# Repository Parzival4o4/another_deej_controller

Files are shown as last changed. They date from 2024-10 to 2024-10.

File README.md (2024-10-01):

# another_deej_controller

This project features an under-the-desk-style volume mixer with six rotary encoders for controlling individual audio channels on your PC, a display for visual feedback, and an air quality sensor that I had lying around.

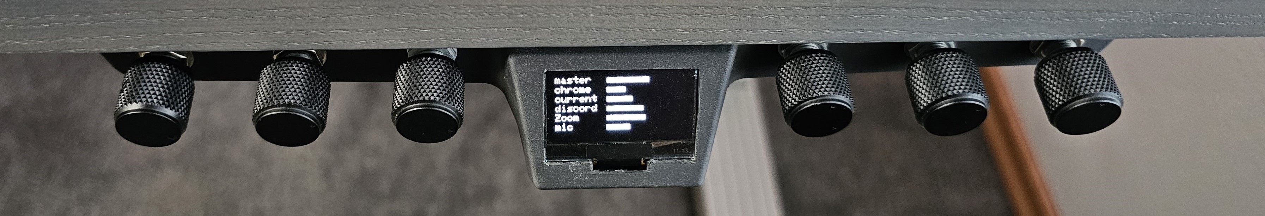
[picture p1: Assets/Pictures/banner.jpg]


For those who don’t know what Deej is: 
Deej is an open-source project by omriharel that enables users to control individual application audio levels on your PC using a DIY Volume Mixer.

My project focuses on building a volume mixer with additional advanced features. For the mixer to function, the PC still needs to be running the Deej software, which you can get from omriharel's [deej project github page](https://github.com/omriharel/deej)

The primary aim of this project was to learn and gain hands-on experience, so I decided to incorporate some non-essential features, which added complexity. If you're looking to build a more basic volume mixer, I highly recommend following the instructions provided by the original Deej project.

# Overview
Cutting_Diagram

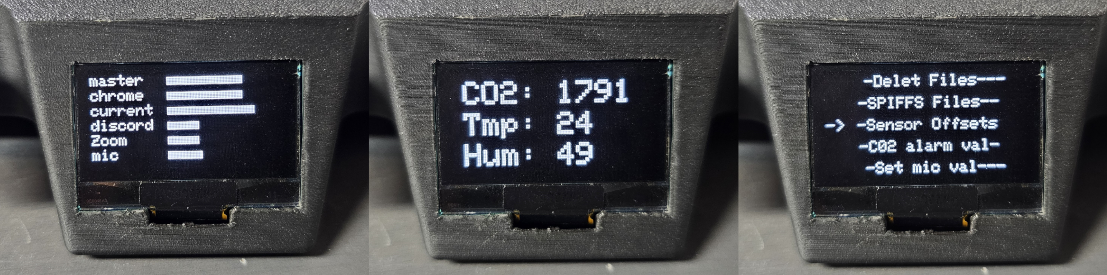
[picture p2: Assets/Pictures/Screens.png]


## How to use

While the mixer controls six volume levels, the channels are not mapped one-to-one with the rotary encoders. I found that I only need fine control over five audio channels: Master, Chrome, Current, Discord, and Zoom.

For my microphone, I prefer it either completely muted or set to its default volume (roughly 43%). Because of this, Encoder 4 is dedicated to controlling device settings, and the microphone volume is instead managed with the buttons on Encoders 5 and 6.

Here’s an overview of what each encoder does on the home screen (encoders numbered from left to right):

| Encoder # | Label | Rotation | Short Press | Long Press | Hold |
| --- | --- | --- | --- | --- | ---|
| 1 | MasterVolume | Volume up/down | Mute/Unmute | Save current volume levels | - |
| 2 | Chrome | Volume up/down | Mute/Unmute | Turn screen off (screen will turn back on when any encoder is rotated or pressed) | - |
| 3 | Current | Volume up/down | Mute/Unmute | - | - |
| 4 | Menu Encoder | Enter settings | Show air quality | - | - |
| 5 | Discord | Volume up/down | Mute the mic channel | Unmute mic channel | - |
| 6 | Zoom | Volume up/down | - | - | Boost mic channel to 100% (for when you need to win an argument 😉)  |
 
## Other random Features

- **Sleep Mode**: If the IR sensor doesn't detect your presence, the screen will turn off until you return to your desk or move one of the knobs.

- **CO2 Alert**: If the CO2 sensor detects that levels exceed the set threshold (which can be configured in the settings menu), an alert will display on the screen, reminding you to let in some fresh air. You can dismiss the alert by moving any of the knobs, but it will return after 15 minutes if levels remain high.

- **Saving Slider Values**: By long-pressing Encoder 1, the current slider values will be saved to local storage. When the device restarts, these values will be loaded automatically (even after a power loss).

# Build 

I attempted to minimize soldering as much as possible. However, since the pins on the encoders are too small to securely fit standard jumper cables, soldering the cables to the pins is necessary.

## Parts

| Quantity | Part | 
| --- | --- |
| 6x | Rotary encoder with switch, 20 pulses per revolution (EN11-HSM1BF20 or EC11)
| 6x | Knob for rotary shaft, 6mm (pay attention if your encoders have D-type or star shape shaft)
| 1x | ESP32 Development Board (preferably with USB-C)
| 1x | PCF8575 IO Expander I2C (16IO pins)
| 1x | SCD40 or SCD41 CO₂ Sensor I2C (optional)
| 1x | AM312 DC 2.7-12V PIR Human Sensor
| 1x | 1.3-Inch OLED Display I2C (not SPI)
| 1x | Breadboard (MB-102)
| ?x | Some jumper cables
| 4x | M3 screws (no longer than 8mm)
| 1x | Double-sided tape
| (1x) | 3D printed case

## Flash ESP32

1. Download the Arduino IDE  https://www.arduino.cc/en/software

2. Pull the Arduino project directory from this repository.

3. On your local system, navigate into the directory and open any of the `.ino` files with the Arduino IDE. The rest of the project files should load automatically 

4. Use the Board Manager to install the ESP32 package by Espressif Systems (version 3.0.5).

5. Use the Library Manager to install the following libraries:
   - **PCF8575** (by Rob Tillart, version 0.2.3)
   - **Sensirion I2C SCD4X** (by Sensirion, version 0.4.0)
   - **Adafruit SH110X** (by Adafruit, version 2.1.11)

6. Select the board under **Tools** -> **Board**.

7. Select the COM port that your ESP32 is connected to.

8. Click the **Upload** button.

    (you might need to hold down the boot button on your ESP23 board during the Upload)

## 3D Printing

The case could still use some optimization to improve printability.

- The main body must be printed with supports, which can be tricky to remove from the cavity in the display section. I had good results using tree supports.
    
    Even with perfect print quality, my design makes it difficult (but not impossible) to maneuver the display into place.

- The lid is printed standing on edge. The model includes some stabilizing fins to prevent it from falling over during printing. Due to the small contact area with the bed, you might also want to use a brim.

If you use Bambu Studio, you can grab the *Case_BambuStudio.3mf* file with all the settings that worked for me. If not, you can use the STEP files. I also included the Autodesk Fusion project if you want to make changes to the model.

## Assembly  

### 1. Cutting the breadboard

The case is too small for a full-sized breadboard to fit, but a half-sized breadboard is too small to accommodate all the components. So, a full-sized breadboard needs to be cut down.

Additionally, the breadboard needs to be split down the middle due to the wide footprint of the ESP32.

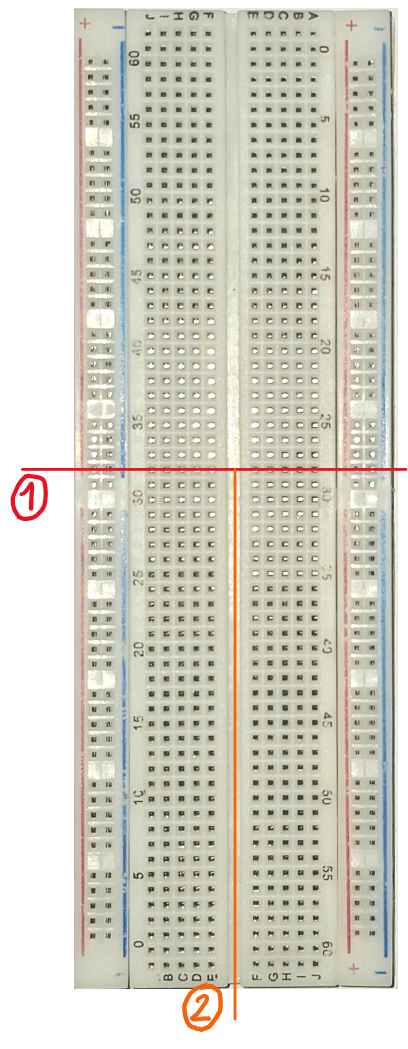
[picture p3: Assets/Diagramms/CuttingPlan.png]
Cutting_Diagram


### 2. Encoder prep:

I prefer smooth rotary encoders for my volume control, but I found no place to buy them. Luckily, it’s possible to modify a step encoder. (If you choose to modify your encoders, keep one stock as the menu encoder should have steps.)

- **Step 1**: Open the encoder.
- **Step 2**: Locate the spring that pushes on the notches.
- **Step 3**: Rip out the spring.
- **Step 4 (optional)**: Add some thick **NON-CONDUCTIVE** grease (I used silicone grease). The grease will increase resistance during rotation, making the encoder feel smoother.
- **Step 5**: Reassemble the encoder.

### 3. Wiring
    
1. Start by populating the breadboard as shown below:

    (For the connections on the breadboard, use small bent wire.)

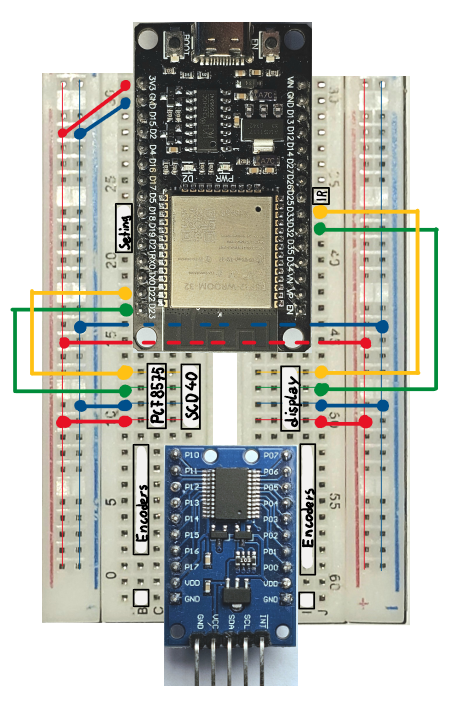
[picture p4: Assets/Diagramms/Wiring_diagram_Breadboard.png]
Wiring_Diagram 1
    

2. Next, solder the jumper cables to your encoders.
3. Solder the ground wires to the encoders (you should have two sets of three encoders).
4. Now, plug everything together.

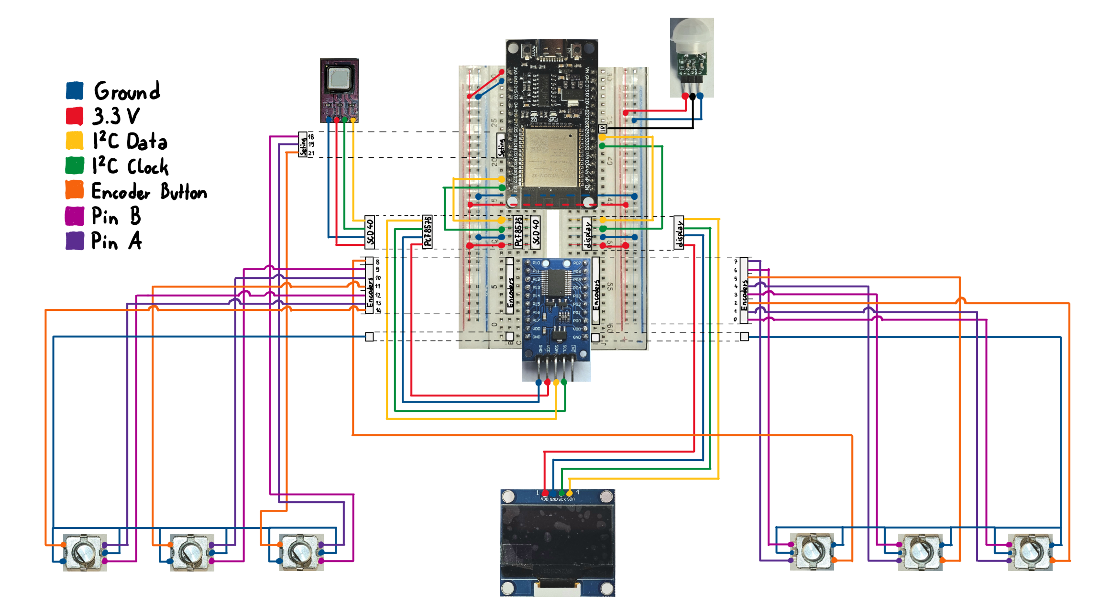
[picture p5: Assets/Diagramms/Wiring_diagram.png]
Wiring_Diagram 3
    

### 4. Stuff everything into the Case

- Use some double-sided tape to hold the SCD40 sensor in place.

- The display can be quite tricky (sorry):

    Cut off the small part of the connector pins sticking out the front; this will allow the display to sit flush.

    Maneuver the display into place. Depending on your print quality, you might need to clean up the print.

    Once in place, tape or glue it down to ensure it doesn't accidentally get pushed back into the case later.

- Stick down the breadboard with the port of the ESP32 sticking out the back. This will allow you to access the reset and boot buttons.

- Bend over the jumper cables on the breadboard. I wanted to make the case as thin as possible, and if the jumper cables stick straight up, the lid can't be closed. 

- Everything else should be straightforward.

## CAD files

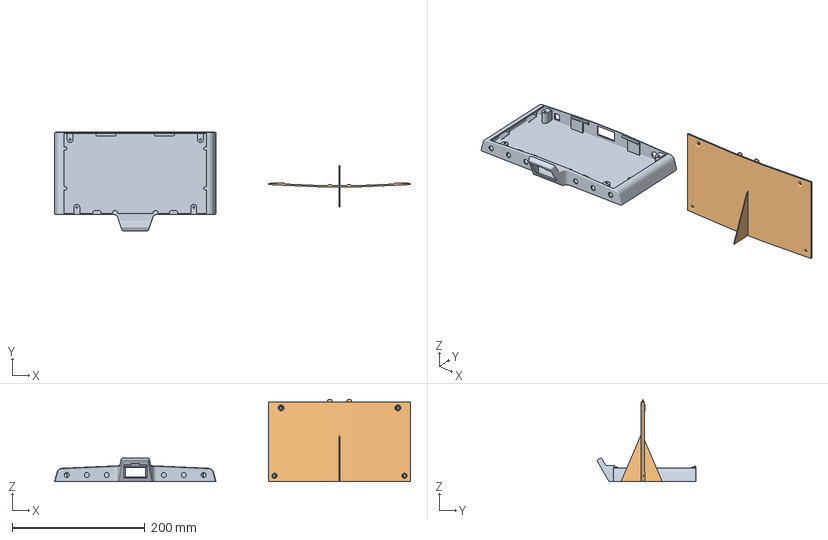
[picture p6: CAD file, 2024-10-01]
Case/Case_BambuStudio.3mf
535.6 x 148.2 x 123.9 mm
Deej Case.step
Deej Deckel.step

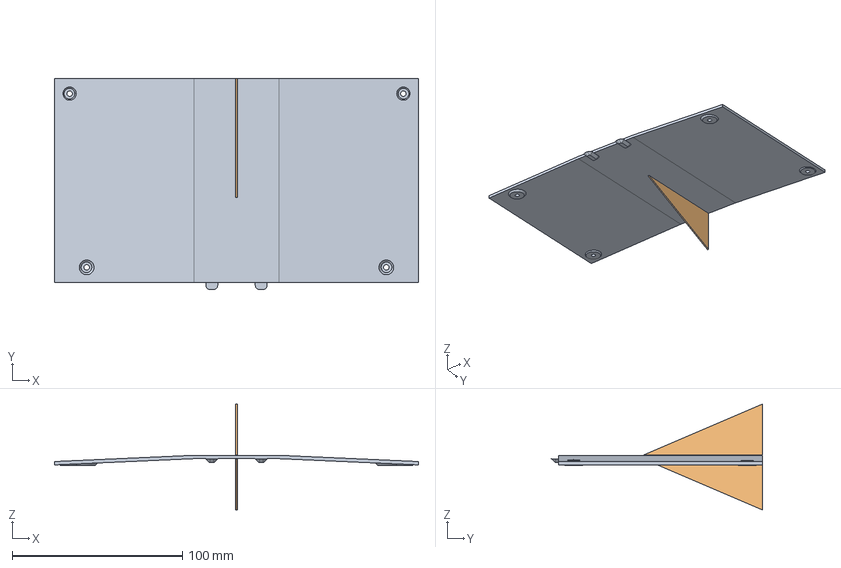
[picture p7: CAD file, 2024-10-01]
Case/Step_Files/case_lid_supported.step
213.7 x 123.9 x 62.2 mm

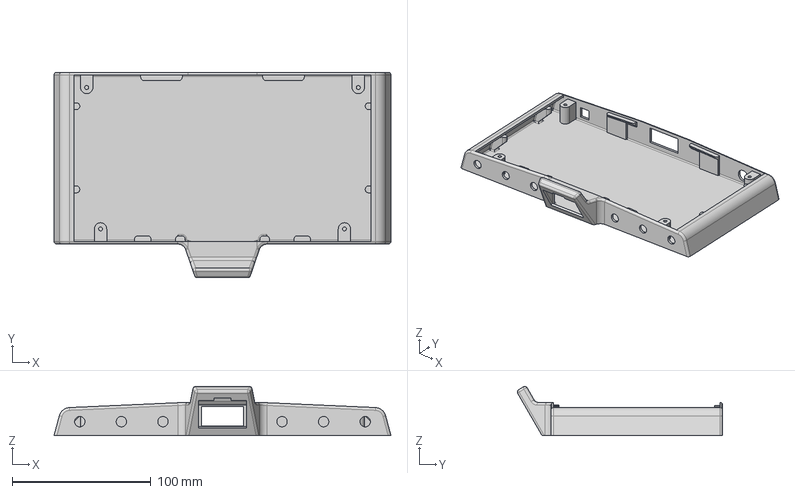
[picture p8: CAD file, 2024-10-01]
Case/Step_Files/case_body.step
243.1 x 148.2 x 35.4 mm

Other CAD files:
Case/Autodesk_Fusion_Project/deej_controller.f3d

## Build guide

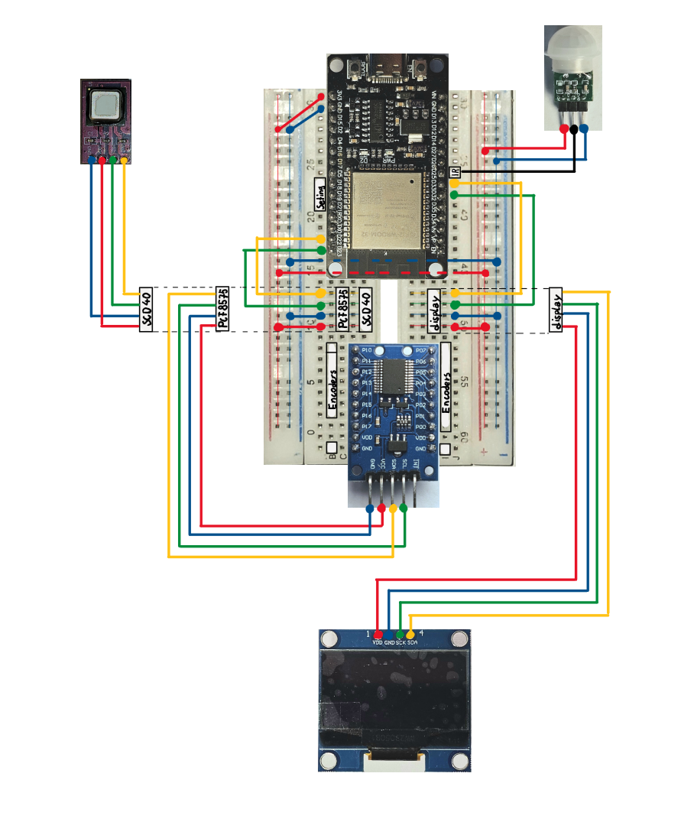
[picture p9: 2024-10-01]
Assets/Diagramms/Wiring_Diagram_No_Encoder.png

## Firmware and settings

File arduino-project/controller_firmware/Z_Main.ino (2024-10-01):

//######################################################################
//##############        _      ____   ____  _____         ##############
//##############       | |    / __ \ / __ \|  __ \        ##############
//##############       | |   | |  | | |  | | |__) |       ##############
//##############       | |   | |  | | |  | |  ___/        ##############
//##############       | |___| |__| | |__| | |            ##############
//##############       |______\____/ \____/|_|            ##############
//##############                                          ##############
//######################################################################


long display_time = 0;

long my_time = 0;
void loop() {
  //long time2 = micros() - my_time;
  //my_time = micros();
  //println("time = " + String(time2) + " free heap: " + String(ESP.getFreeHeap()));
  //println(String(time2));


  // ====== Check panic ======
  if (loop_debug()) { return; }

  // ====== sensors ======
  std::vector<std::unique_ptr<StateChange>> sensors;
  I_state.check_sensors(sensors);
  for (const auto& sc : sensors) {
    mm.handle_sensors(sc, &state);
  }

  // ==== user input ====
  std::vector<std::unique_ptr<StateChange>> inputs;
  I_state.check_input(inputs);
  if (!inputs.empty()){
    state.action(); 
  } else if (millis() - state.get_last_action() > (SCREEN_TIMEOUT * 60000)) {
    inputs.push_back(make_unique<InactiveChange>(true));
  }
  // call mode handler
  // call default handler
  for (const auto& sc : inputs) {
    mm.handle_input(sc, &state);
  }

  // ==== idle tasks ====
  mm.idle_task(&state);
  
  // === display/send ===
  state.get_deej()->send_sliders();
  mm.display_state(&state);


  //println(String(micros() - my_time));
}

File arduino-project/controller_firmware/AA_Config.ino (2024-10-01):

//################################################
//                  Hardware
//################################################

//---- Wire 0 ----
// IO expander, scd4X,
//esp8266 scl = D1 = 5; sda = D2 = 4
//esp32
#define WIRE0_SCL 23        //positive int (esp pin)
#define WIRE0_SDA 22        //positive int (esp pin)
#define WIRE0_SPEED 400000  // default speed is 100000 max is 400000 oc up to 700000

//---- Wire 1 ----
// Display (sending a new frame to a display can take around 30 ms, which is wy it gets its own bus and threat)
// esp32 (in my configuration): scl = 32, sda = 33
#define WIRE1_SCL 32        //positive int (esp pin)
#define WIRE1_SDA 33        //positive int (esp pin)
#define WIRE1_SPEED 100000  // default speed is 100000 max is 400000 oc up to 700000


//---- PCF8575 ----
#define PCF8575_ADDRESS 0x20  // default address is 0x20 (address min 0x20 max 0x27)

//---- SCD4X Sensor ----
#define SCD_interval_slow 60000  //SCD_interval_slow>0 // millis between measurements
#define SCD_interval_fast 5000   //SCD_interval_fast>0 // millis between measurements

//---- Movement Sensor ----
#define MOTION_PIN 25          //positive int (esp pin) // GPIO 25 in my build
#define Movement_interval 2000  //Movement_interval > 0 // most movement sensor hold the pin signal for some time

//---- Encoder -----
#define ENCODER_COUNT 6  //number of encoders (int)

#define ENCODER_PIN_A \
  { 1, 4, 7, 19, 10, 13 }  //int[]
#define ENCODER_PIN_B \
  { 0, 3, 6, 18, 9, 12 }  //int[]
#define ENCODER_PIN_S \
  { 2, 5, 8, 21, 11, 14 }  //int[]
#define ENCODER_CONNECTED_TO \
  { 1, 1, 1, 0, 1, 1 }  //int[] // 1 connoted to IO Expander 0 connected to ESP

#define ENCODER_MENU 3  //int //if you want to change this you probably will need to change more in the code just leaf it at 3 // 0 < ENCODER_MENU < ENCODER_COUNT

#define ENCODER_ROT_CHANGE_BLOCK_TIME 1  // millis > 0 // blocks a change in rotation direction for the number of millis

//---- Display ----
#define SCREEN_WIDTH 128  //int //program dose not support scaling.
#define SCREEN_HEIGHT 64  //int //dont change
#define FPS 28            //int // min=1 max=30


//################################################
//                  Software
//################################################

//---- file system ----
#define FILE_NAME_SLIDER_VALUES "/slider_values.bin"
#define FILE_NAME_STATE_CONFIG "/state_config.bin"


//---- Serial speed ----
#define SERIAL_SPEED 4800 //115200  //int

//---- Encoder and swich stuff ----
#define IGNORE_ROTATION_TIME 20  // millis, for how long should rotation be ignored after button release

//        once rotation on one encoder is detected all other encoders will be ignored (both button and rotation)
//        this PRIO_TIME defines for how long after the rotation ends the encoder will be prioritized
#define PRIO_TIME 100

//---- Screen off timer -----
#define SCREEN_TIMEOUT 10  // minutes, how long should the program wait to turn of the screen

//---- deej ----
#define DELAY_AFTER_SENDING 8  //positive // millis
#define SLIDER_COUNT 6         // positive // this dose not have to be the same value as ENCODER_COUNT
#define DEFAULT_PERCENT \
  { 75, 50, 50, 75, 50, 43 }  // default volume levels

#define MIC_BOOST_PERCENT 100  // positive 0-100 
#define DEAD_ZONE_PERCENT 50   //  0<= DEAD_ZONE_PERCENT <= 100

#define DEEJ_MAX_VAL 1023  //dont change this // should be 1023

//---- co2 alarm ----
#define CO2_ALARM_LEVEL 1100 //int > 0 //by default if co2 is higher than this an alarm is triggered 

#define CO2_ALARM_MUTE_TIME 15 //int > 0 //minutes 

//################################################
//                  Input
//################################################

//---- switch ----
// any press less than this is short every thing more is a long press
#define SHORT_PRESS_CUT_OF 650  // int, positive, millis


//################################################
//                  Debug
//################################################
#define DEBUG false  //bool //prints free heap and some test text if defined

#define PRINT_ERR true  //bool

#define ENABLE_PANIC true  //bool //true: errors will break the program; false: errors will cause undefined behavior

#define DEEJ_PRINT true  //bool //for debuting it can be useful to disable the deej messages

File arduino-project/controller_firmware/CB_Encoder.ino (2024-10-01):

PCF8575 PCF(0x20, &Wire);

//##########################################
class Encoder_State {
  //########################################
  /**this represents a single encoder**/
protected:
  //pins
  int pin_a;
  int pin_b;
  int pin_s;
  int connected_to;
  //rot state
  int old_rot_pos = 0;
  int rot_dir = 0;
  unsigned long state_time = 0;  // millis();  //time since state change (if a skip is detected this is not updated)
  //switch state
  bool old_switch_state = false;
  bool is_long_press = false;
  int switch_press_start = -1;
  static constexpr int debounce = 5; //ms // time after state change that further state change is ignored;
  long debounce_time = 0; 

  bool read_pin(int16_t pinStates, int pin) {
    switch (connected_to) {
      case 0:
        return !digitalRead(pin);
      case 1:
        return !bitRead(pinStates, pin);
      default:
        my_panic("connection type is not supported check the ENCODER_CONNECTED_TO array in the config");
        return 0;
    }
  }

  int read_rot_pos(int16_t pinStates) {
    bool A = read_pin(pinStates, pin_a);
    bool B = read_pin(pinStates, pin_b);
    if (A && B) {
      return 0;
    } else if (!A && B) {
      return 1;
    } else if (!A && !B) {
      return 2;
    } else if (A && !B) {
      return 3;
    }
    my_panic("reached unreachable code in read_rot_pos()");
    return 0;
  }

  SWITCH_PRESS checkSwitch(bool new_switch_state) {
    //== debounce ==
    if (new_switch_state != old_switch_state) {
      if ((millis() - debounce_time) > debounce){
        //outside of debounce time -> allow state change and begin debounce time;
        debounce_time = millis();
      } else {
        //within debounce time -> dont allow state change 
        if (old_switch_state){
          return PRESSED;
        } else {
          return NOT_PRESSED;
        }
      }
    }
    //== actual check ==
    // switch state == true -> switch pressed
    //switch is and was not pressed -> no state change return no
    if (!new_switch_state && !old_switch_state) {
      // old and new are the same no need to set old = new
      return NOT_PRESSED;
    }
    //switch was just pressed -> start timer, is long false, update state
    if (new_switch_state && !old_switch_state) {
      old_switch_state = new_switch_state;  //switch is pressed
      switch_press_start = millis();
      is_long_press = false;
      return JUST_PRESSED;  //short press is signaled on release
    }
    //switch was released -> check if its short press
    if (!new_switch_state && old_switch_state) {
      old_switch_state = new_switch_state;
      if (!is_long_press) {
        return SHORT_PRESS;
      } else {
        is_long_press = false;  // redundant
        return RELEASED;     // useful for mic boost 
      }
    }
    //switch continues to be pressed -> check short press cut of time
    if (new_switch_state && old_switch_state) {
      // old and new are the same no need to set old = new
      if (!is_long_press && (millis() - switch_press_start > SHORT_PRESS_CUT_OF)) {
        //switch is long pressed
        is_long_press = true;
        return LONG_PRESS;
      } else {
        // no state change
        return PRESSED;
      }
    }
    my_panic("checkSwitch(): a unreachable stat was reached");
    return NOT_PRESSED;
  }

  // helper function for checkRotation
  int rot_by_one(int dir, int new_rot_pos) {
    //direction has to be either 1 or -1

    // debounce dose not prevent doubled inputs and apparently there are still missing inputs
    // but the result might be acceptable
    if (rot_dir != dir && millis() - state_time < ENCODER_ROT_CHANGE_BLOCK_TIME) {
      // new rotation direction was seen and the block time is not over -> ignore change (debounce)
      // we also do not set the old_rot_pos
      return 0;
    }
    old_rot_pos = new_rot_pos;
    state_time = millis();
    rot_dir = dir;
    return dir;
  }

  // helper function for checkRotation
  int skipped_setp(int new_rot_pos) {
    old_rot_pos = new_rot_pos;
    state_time = millis();
    // we skiped a step and dont know the turning direction
    // use most probable rotation
    if (rot_dir > 0) {
      return 2;
    } else {
      return -2;
    }
  }

  int checkRotation(int new_rot_pos) {
    switch (old_rot_pos) {
      // ----- previous postion 0 -----
      case 0:
        switch (new_rot_pos) {
          case 0:  // same position
            return 0;
          case 1:  // right turn +1
            return rot_by_one(1, new_rot_pos);
          case 3:  // left turn -1
            return rot_by_one(-1, new_rot_pos);
          case 2:  // skipped
            return skipped_setp(new_rot_pos);
        }
        break;
      // ----- previous postion 1 -----
      case 1:
        switch (new_rot_pos) {
          case 1:  // same position
            return 0;
          case 2:  // right turn +1
            return rot_by_one(1, new_rot_pos);
          case 0:  // left turn -1
            return rot_by_one(-1, new_rot_pos);
          case 3:  // skipped
            return skipped_setp(new_rot_pos);
        }
        break;
      // ----- previous postion 2 -----
      case 2:
        switch (new_rot_pos) {
          case 2:  // same position
            return 0;
          case 3:  // right turn +1
            return rot_by_one(1, new_rot_pos);
          case 1:  // left turn -1
            return rot_by_one(-1, new_rot_pos);
          case 0:  // skipped
            return skipped_setp(new_rot_pos);
        }
        break;
      // ----- previous postion 3 -----
      case 3:
        switch (new_rot_pos) {
          case 3:  // same position
            return 0;
          case 0:  // right turn +1
            return rot_by_one(1, new_rot_pos);
          case 2:  // left turn -1
            return rot_by_one(-1, new_rot_pos);
          case 1:  // skipped
            return skipped_setp(new_rot_pos);
        }
        break;
    }
    my_panic("checkRotation(): a unreachable state was reached\n old_rotpos " + String(old_rot_pos) + " new_rotpos " + String(new_rot_pos));
    return 0;
  }

  void setup(int a, int b, int s, int c, int16_t pinStates) {
    // call this function in the childs constructor
    if (c == 0) {
      // encoder is connected to the esp directly -> setup pins
      pinMode(pin_a, INPUT_PULLUP);
      pinMode(pin_b, INPUT_PULLUP);
      pinMode(pin_s, INPUT_PULLUP);
    }
    get_button_StatChange(pinStates);
    get_rot_StatChange(pinStates);
  }

public:
  Encoder_State(int a, int b, int s, int c)
    : pin_a(a), pin_b(b), pin_s(s), connected_to(c) {
  }

  ~Encoder_State() {}

  SWITCH_PRESS get_button_StatChange(int16_t pinStates) {
    return checkSwitch(read_pin(pinStates, pin_s));
  }

  virtual int get_rot_StatChange(int16_t pinStates);

  virtual bool need_prio();
};
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

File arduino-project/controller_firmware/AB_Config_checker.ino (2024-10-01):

//##########################################
//         function definitions 
//##########################################
bool is_bool(int x);
bool check_array_values_in_range(int arr[], int min, int max);
bool check_array_values_positive(int arr[]);
void check_config();
bool check_serial_config();


/**
 *@brief checks the entirety of the config
 *
 * Checking is handled in one big function to (hopefully) avoid me forgetting to check a value 
 * (Easier to keep track, if its all in one place)
 *
 */
void check_config() {
  todo("change all values of the Config to strictly uppercase");

  //################################################
  //                  Hardware
  //################################################
  //---- Wire 0 ----
  if (WIRE0_SCL < 0) {
    my_panic("WIRE0_SCL is a pin on the micro controller and should be positive: " + String(WIRE0_SCL));
  }
  if (WIRE0_SDA < 0) {
    my_panic("WIRE0_SDA is a pin on the micro controller and should be positive: " + String(WIRE0_SDA));
  }
  if (WIRE0_SPEED < 100000 || WIRE0_SPEED > 700000) {
    my_panic("WIRE0_SPEED is out of range: " + String(WIRE0_SPEED));
  }
  //---- Wire 1 ----
  if (WIRE1_SCL < 0) {
    my_panic("WIRE1_SCL is a pin on the micro controller and should be positive: " + String(WIRE1_SCL));
  }
  if (WIRE1_SDA < 0) {
    my_panic("WIRE1_SDA is a pin on the micro controller and should be positive: " + String(WIRE1_SDA));
  }
  if (WIRE1_SPEED < 100000 || WIRE1_SPEED > 700000) {
    my_panic("WIRE1_SPEED is out of range: " + String(WIRE1_SPEED));
  }
  //---- PCF8575 ----
  if (PCF8575_ADDRESS < 0x20 || PCF8575_ADDRESS > 0x27) {
    my_panic("PCF8575_ADDRESS should be between 0x20 and 0x27 default is 0x20: " + String(PCF8575_ADDRESS));
  }
  //---- SCD4X Sensor ----
  if (SCD_interval_slow <= 0 ){
    my_panic("SCD_interval_slow should be positive: "  + String(SCD_interval_slow));
  }
  if (SCD_interval_fast <= 0 ){
    my_panic("SCD_interval_fast should be positive: "  + String(SCD_interval_slow));
  }
  //---- Movement Sensor ----
  if (Movement_interval < 0) {
    my_panic("Movement_interval should be positive: "  + String(Movement_interval));
  }
  //---- Encoder -----
  if (ENCODER_COUNT < 0) {
    my_panic("ENCODER_COUNT should be a int bigger 0: " + String(ENCODER_COUNT));
  }
  int Pin_A[] = ENCODER_PIN_A;
  int Pin_B[] = ENCODER_PIN_B;
  int Pin_S[] = ENCODER_PIN_S;
  int connected_to[] = ENCODER_CONNECTED_TO;
  if (!(sizeof(Pin_A) / sizeof(Pin_A[0]) == ENCODER_COUNT)) {
    my_panic("Pin_A arrays has the wrong size");
  }
  if (!(sizeof(Pin_B) / sizeof(Pin_B[0]) == ENCODER_COUNT)) {
    my_panic("Pin_B arrays has the wrong size");
  }
  if (!(sizeof(Pin_S) / sizeof(Pin_S[0]) == ENCODER_COUNT)) {
    my_panic("Pin_S arrays has the wrong size");
  }
  if (!(sizeof(connected_to) / sizeof(connected_to[0]) == ENCODER_COUNT)) {
    my_panic("connected_to arrays has the wrong size");
  }
  if (!(check_array_values_positive(Pin_A) && check_array_values_positive(Pin_B) && check_array_values_positive(Pin_S))) {
    my_panic("one of the ENCODER_PIN arrays contains a negative value");
  }
  if (!check_array_values_in_range(connected_to, 0, 1)) {
    my_panic("ENCODER_CONNECTED_TO contains a invalid value (min: 0, max: 1): ");
  }
  if (!(0 <= ENCODER_MENU && ENCODER_MENU <= ENCODER_COUNT)) {
    my_panic("ENCODER_MENU is invalid: " + String(ENCODER_MENU));
  }
  if (ENCODER_MENU != 3){
    my_panic("ENCODER_MENU should be 3: " + String(ENCODER_MENU));
  }
  //---- Display ----
  if (SCREEN_WIDTH != 128 && SCREEN_HEIGHT != 64) {
    my_panic("SCREEN_WIDTH is not 128 and or SCREEN_HEIGHT is not 64");
  }
  if (ENCODER_ROT_CHANGE_BLOCK_TIME < 0) {
    my_panic("ENCODER_ROT_CHANGE_BLOCK_TIME should be positive: "  + String(ENCODER_ROT_CHANGE_BLOCK_TIME));
  }
  if (FPS<1 || FPS>30){
    my_panic("FPS is not set to a value in range of 1-30: " + String(FPS));
  }

  //################################################
  //                  Software
  //################################################

  // Serial (redundant)
  if (!check_serial_config()) {
    my_panic("config has invalid Serial speed");  // can not be printed since the serial dose not work duh
  }

  if (IGNORE_ROTATION_TIME < 0) {
    my_panic("IGNORE_ROTATION_TIME should be positive as it represents a time: " + String(IGNORE_ROTATION_TIME));
  }

  if (SCREEN_TIMEOUT < 0) {
    my_panic("SCREEN_TIMEOUT should be positive as it represents a time: " + String(SCREEN_TIMEOUT));
  }

  //---- deej ----
  if (DELAY_AFTER_SENDING < 0){
    my_panic("DELAY_AFTER_SENDING should be bigger 0: " + String(DELAY_AFTER_SENDING));
  }

  if ( SLIDER_COUNT < 0) {
    my_panic("SLIDER_COUNT should be a int bigger 0: " + String(SLIDER_COUNT));
  }

  int def_pro[] = DEFAULT_PERCENT; 

  if (!(sizeof(def_pro) / sizeof(def_pro[0]) == SLIDER_COUNT)){
    my_panic("DEFAULT_PERCENT arrays has the wrong size");
  }
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
